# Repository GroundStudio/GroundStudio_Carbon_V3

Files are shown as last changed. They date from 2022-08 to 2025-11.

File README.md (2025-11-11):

GroundStudio Carbon V3
====================================
CYQ2 (https://ardushop.ro/en/electronics/537-placa-de-dezvoltare-carbon-v3-6427854000392.html)

Get it from [ardushop.ro](https://ardushop.ro/en/electronics/537-placa-de-dezvoltare-carbon-v3-6427854000392.html)

Explore all the GroundStudio products at [ardushop.ro](https://ardushop.ro/en/37-groundstudio)

Description
-------------------
Features ESP32 based Pico V3-02 with 2.4 GHz WiFi, V4.2 Bluetooth, 8MB SPI Flash, 2MB SPI PSRAM, 520kB internal SRAM, 448kB ROM, 18 GPIO, 12 ADC and 6 touch sensitive pins, I²C 3V3 adapter, RGB smart LED, 1 cell LiPo/LiIon battery charger with optional battery connector and CH340C for USB comunication.

Contents
-------------------

* [/Documentation](https://github.com/GroundStudio/GroundStudio_Carbon_V3/tree/main/Documentation) -- Pinout.
* [/Hardware](https://github.com/GroundStudio/GroundStudio_Carbon_V3/tree/main/Hardware) -- Schematics, layout.
* [/Arduino](https://github.com/GroundStudio/GroundStudio_Carbon_V3/tree/main/Arduino/Examples) -- Arduino test examples.

Versions
-------------------
*(Not all tags shown)*

- [REV 0.0.2]:
  - testing different uart pins setup

- [REV 0.0.3]:
  - added test point for GPIO0
  - added 100nF in parallel with R14 for better battery voltage level reading
  - adjusted the position of pin labels for better visibility

License
-------------------

This is released under the [Attribution-ShareAlike 4.0 International (CC BY-SA 4.0)](https://creativecommons.org/licenses/by-sa/4.0/) license.
**You are welcome to use this for commercial purposes.**

Please consider contributing back to this project or others to help the open-source hardware community continue to thrive and grow!

Certifications:

[Open Source Hardware Association](https://certification.oshwa.org/ro000007.html)   
   
certification-mark-RO000007-wide (https://certification.oshwa.org/ro000007.html)

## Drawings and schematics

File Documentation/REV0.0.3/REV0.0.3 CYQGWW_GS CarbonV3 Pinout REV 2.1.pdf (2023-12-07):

# GroundStudio Carbon V3

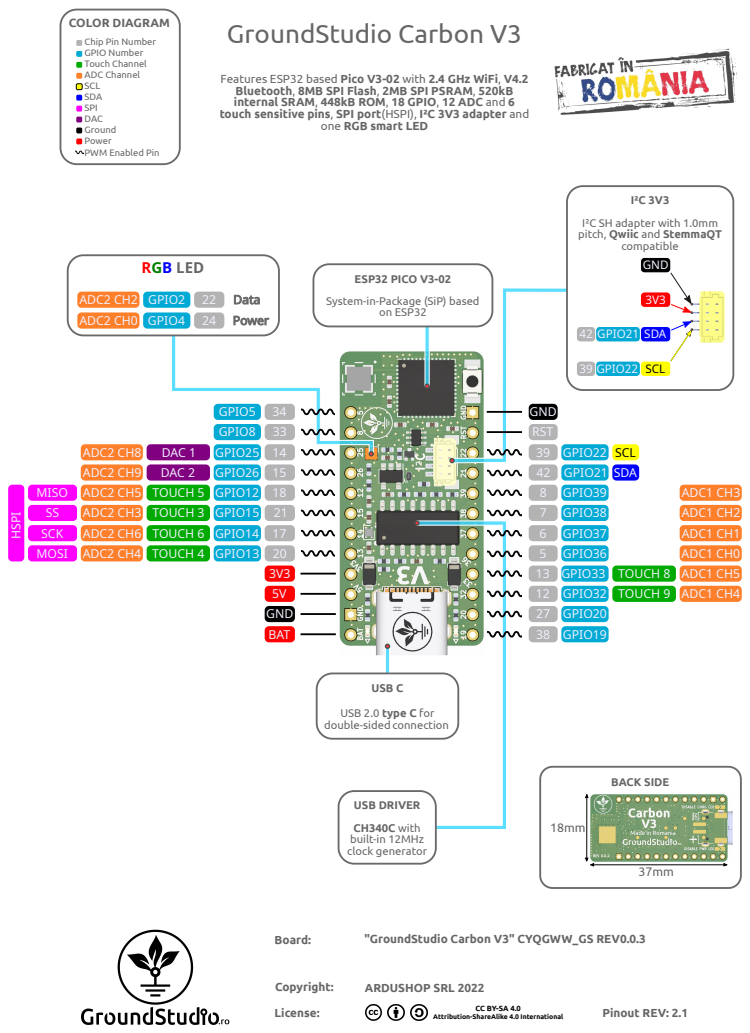
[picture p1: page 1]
COLOR DIAGRAM; Copyright:; License:; ARDUSHOP SRL 2022; Pinout REV: 2.1; Board:; "GroundStudio Carbon V3" CYQGWW_GS REV0.0.3; SCK; MISO; MOSI; on ESP32; BACK SIDE; USB C; GPIO38; GPIO37 GPIO36 GPIO33 GPIO32 GPIO20 GPIO19; 8 GPIO39; TOUCH 8 TOUCH 9; SDA; SCL; ADC1 CH1; ADC1 CH2; ADC1 CH3; ADC1 CH0 ADC1 CH5 ADC1 CH4; GND BAT; DAC 1; TOUCH 5 TOUCH 3 TOUCH 6; DAC 2; TOUCH 4; GND RST; GPIO26 GPIO12 GPIO15 GPIO14; GPIO25; GPIO8; GPIO13; GPIO5; ADC2 CH8 ADC2 CH9 ADC2 CH5 ADC2 CH3 ADC2 CH6 ADC2 CH4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

Chip Pin Number
GPIO Number
Touch Channel
ADC Channel
SCL
SDA
SPI
DAC
Ground
Power
PWM Enabled Pin

Features ESP32 based Pico V3-02 with 2.4 GHz WiFi, V4.2
Bluetooth, 8MB SPI Flash, 2MB SPI PSRAM, 520kB
internal SRAM, 448kB ROM, 18 GPIO, 12 ADC and 6
touch sensitive pins, SPI port(HSPI), I²C 3V3 adapter and

one RGB smart LED

I²C SH adapter with 1.0mm
pitch, Qwiic and StemmaQT

ESP32 PICO V3-02
System-in-Package (SiP) based

USB 2.0 type C for
double-sided connection

Attribution-ShareAlike 4.0 International

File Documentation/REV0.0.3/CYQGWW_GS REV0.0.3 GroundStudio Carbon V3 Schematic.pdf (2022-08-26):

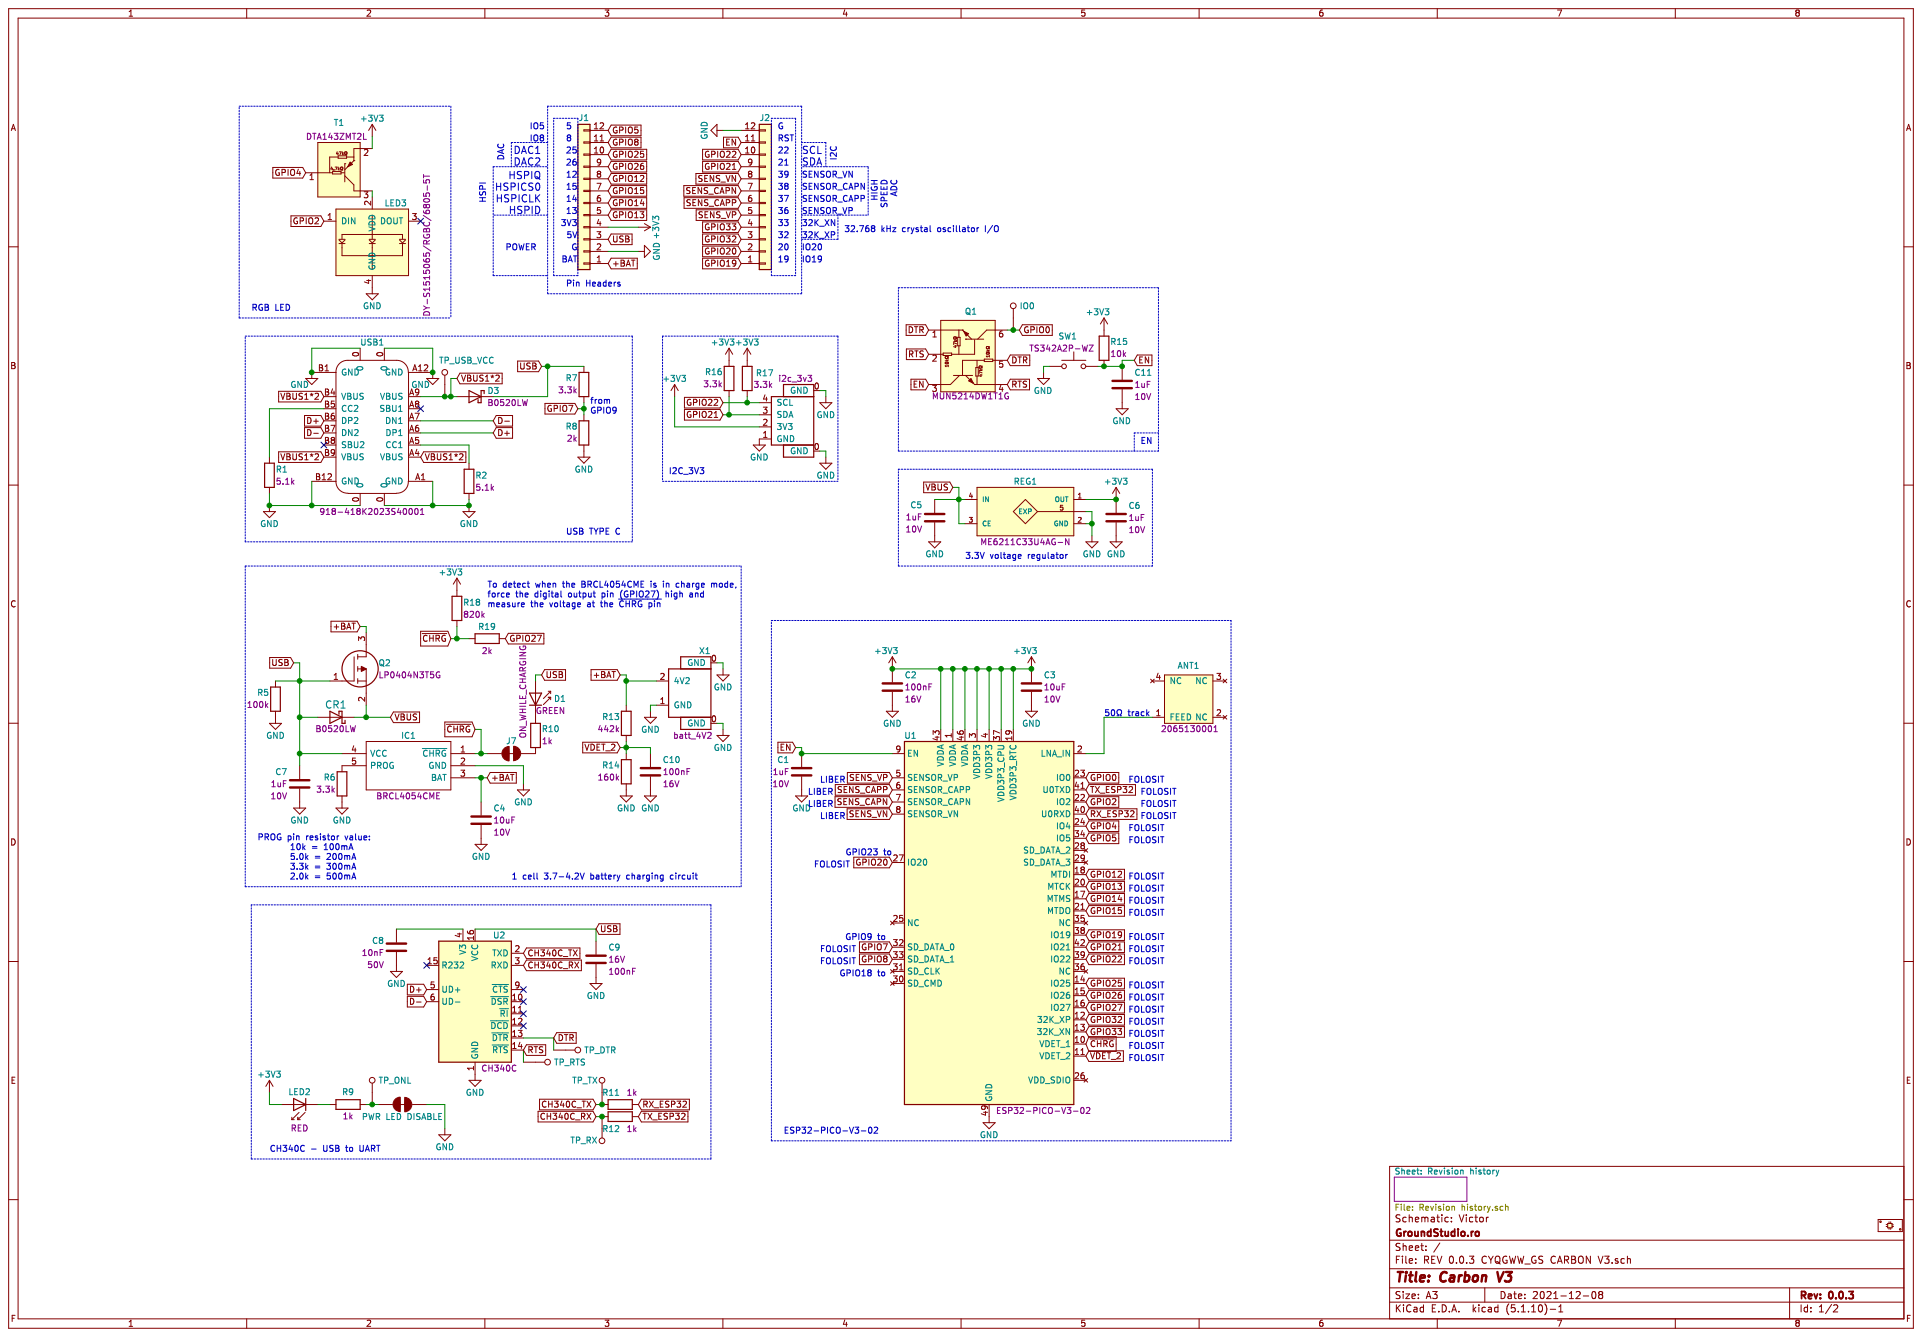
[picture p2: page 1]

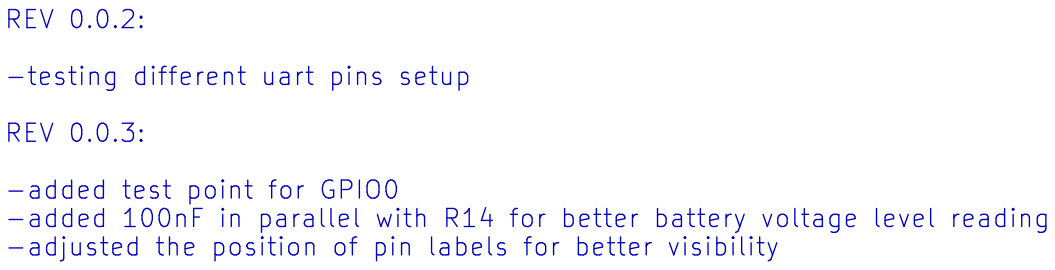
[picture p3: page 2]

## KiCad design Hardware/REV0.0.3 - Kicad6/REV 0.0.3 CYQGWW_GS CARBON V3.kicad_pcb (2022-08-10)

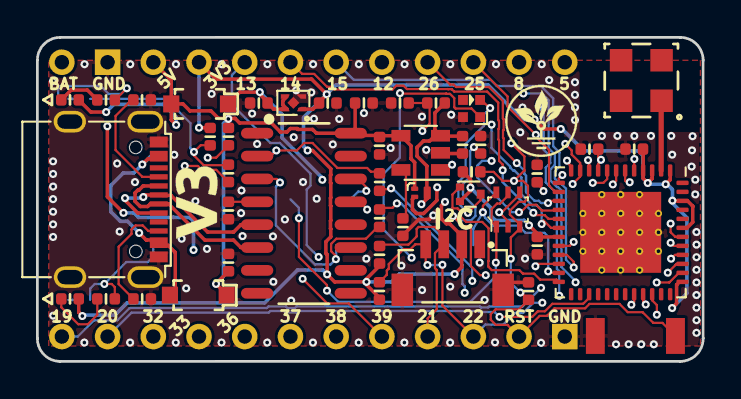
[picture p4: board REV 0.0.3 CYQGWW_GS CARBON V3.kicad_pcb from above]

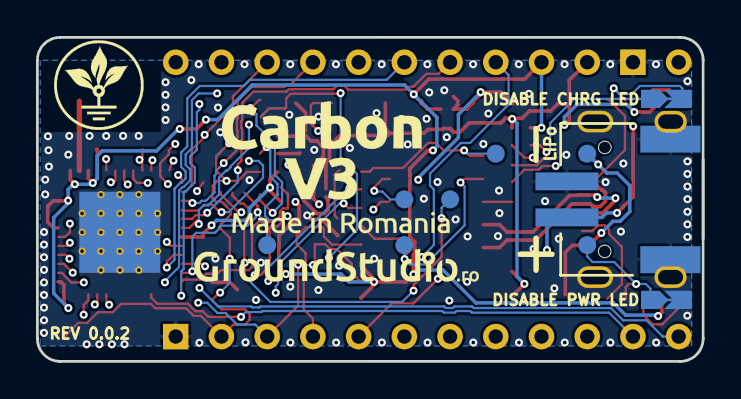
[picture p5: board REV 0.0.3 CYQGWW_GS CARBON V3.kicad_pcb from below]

Board: 4 copper layers, 37.0 x 18.0 mm, 56 parts (5 on the bottom side), 50 nets.

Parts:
ANT1: 2065130001
C1, C5, C6, C7, C11: C_0402_1uF_10V; C_0402_alt
C2, C9, C10: C_0402_100nF_16V; C_0402_alt
C3, C4: C_0402_10uF_10V; C_0402_alt
C8: C_0402_10nF_50V; C_0402_alt
CR1: SOD-123 B0520LW; SOD-123
D1: LED_0402_GREEN; LED_0402_alt
D3: SOD-123 B0520LW; SOD-123
IC1: SOT-23-5 BRCL4054CME; SOT-23-5
J1, J2: PinHeader_1x12_P2.54_V_M A2541WV-12P; PinHeader_1x12_P2.54mm_Vertical_Male
J4: PWR LED DISABLE; SolderJumper_NC
J7: disable CHARGING LED; SolderJumper_NC
LED2: LED_0402_RED; LED_0402_alt
LED3: SK6805-EC15 DY-S1515065; SK6805-EC15
Q1: SOT-363 MUN5214DW1T1G; SOT-363
Q2: SOT-883 LP0404N3T5G; SOT-883
R1, R2: R_0402_5.1k; R_0402_alt
R5: R_0402_100k; R_0402_alt
R6, R7, R16, R17: R_0402_3.3k; R_0402_alt
R8, R19: R_0402_2k; R_0402_alt
R9, R10, R11, R12: R_0402_1k; R_0402_alt
R13: R_0402_442k; R_0402_alt
R14: R_0402_160k; R_0402_alt
R15: R_0402_10k; R_0402_alt
R18: R_0402_820k; R_0402_alt
REG1: FBP1-1-4_ME6211C33U4AG-N; FBP1-1-4
SW1: TS342A2P-WZ
T1: SOT-723_DTA143ZMT2L; SOT-723
TP1: TP_RTS; TestPoint
TP2: IO0; TestPoint
TP3: TP_USB_VCC; TestPoint
TP5: TP_ONL; TestPoint
TP6: TP_TX; TestPoint
TP7: TP_RX; TestPoint
TP8: TP_DTR; TestPoint
U1: QFN-48-7x7mm ESP32-PICO-V3-02; QFN-48-1EP_7x7mm_P0.5mm_EP4.5x4.5mm
U2: SOP-16_150MIL CH340C; SOP-16_150MIL
USB1: USB_C 918-418K2023S40001; USB_C_C167321
X1: PH__1x02_P2.00mm_Horizontal C47647; PH__1x02_P2.00mm_Horizontal
X2: SH__1x04_Vertical C145961; SH__1x04_P1.00mm_Vertical

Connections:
+3V3: C2.1, C3.1, C6.1, J1.4, LED2.2, R15.2, R16.2, R17.1, R18.1, REG1.1, T1.2, U1.1, U1.3, U1.4, U1.19, U1.37, U1.43, U1.46, X2.2
+BAT: C4.1, IC1.3, J1.1, Q2.3, R13.2, X1.2
CH340C_RX: R12.2, TP7.~, U2.3
CH340C_TX: R11.2, TP6.~, U2.2
D+: U2.5, USB1.A6, USB1.B6
D-: U2.6, USB1.A7, USB1.B7
DTR: Q1.1, Q1.5, TP8.~, U2.13
EN: C1.1, C11.1, J2.11, Q1.3, R15.1, SW1.2, U1.9
GND: C1.2, C2.2, C3.2, C4.2, C5.1, C6.2, C7.2, C8.1, C9.2, C10.2, C11.2, IC1.2, J1.2, J2.12, J4.2, LED3.4, R1.2, R2.2, R5.1, R6.1, R8.1, R14.1, REG1.2, REG1.5, SW1.1, U1.49, U2.1, USB1.0, USB1.A1, USB1.A12, USB1.B1, USB1.B12, X1.0, X1.1, X2.0, X2.1
GPIO0: Q1.6, TP2.~, U1.23
GPIO2: LED3.1, U1.22
GPIO4: T1.1, U1.24
GPIO5: J1.12, U1.34
GPIO7: R7.1, R8.2, U1.32
GPIO8: J1.11, U1.33
GPIO12: J1.8, U1.18
GPIO13: J1.5, U1.20
GPIO14: J1.6, U1.17
GPIO15: J1.7, U1.21
GPIO19: J2.1, U1.38
GPIO20: J2.2, U1.27
GPIO21: J2.9, R16.1, U1.42, X2.3
GPIO22: J2.10, R17.2, U1.39, X2.4
GPIO25: J1.10, U1.14
GPIO26: J1.9, U1.15
GPIO27: R19.2, U1.16
GPIO32: J2.3, U1.12
GPIO33: J2.4, U1.13
unnamed: ANT1.1, U1.2
unnamed: C8.2, U2.4
unnamed: D1.1, R10.2
unnamed: IC1.5, R6.2
unnamed: J4.1, R9.2, TP5.~
unnamed: J7.2, R10.1
unnamed: LED2.1, R9.1
unnamed: LED3.2, T1.3
unnamed: R1.1, USB1.B5
unnamed: R2.1, USB1.A5
RTS: Q1.2, Q1.4, TP1.~, U2.14
RX_ESP32: R11.1, U1.40
SENS_CAPN: J2.7, U1.7
SENS_CAPP: J2.6, U1.6
SENS_VN: J2.8, U1.8
SENS_VP: J2.5, U1.5
TX_ESP32: R12.1, U1.41
USB: C7.1, C9.1, CR1.2, D1.2, D3.1, IC1.4, J1.3, Q2.1, R5.2, R7.2, U2.16
VBUS: C5.2, CR1.1, Q2.2, REG1.3, REG1.4
VBUS1*2: D3.2, TP3.~, USB1.A4, USB1.A9, USB1.B4, USB1.B9
VDET_2: C10.1, R13.1, R14.2, U1.11
~CHRG: IC1.1, J7.1, R18.2, R19.1, U1.10

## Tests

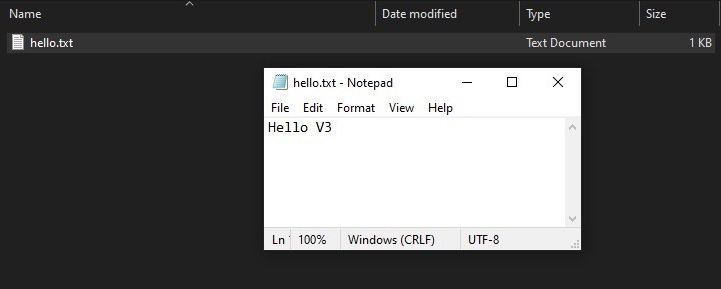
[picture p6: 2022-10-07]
Arduino/Examples/HSPI_SD_card_test/SD test result file.jpg

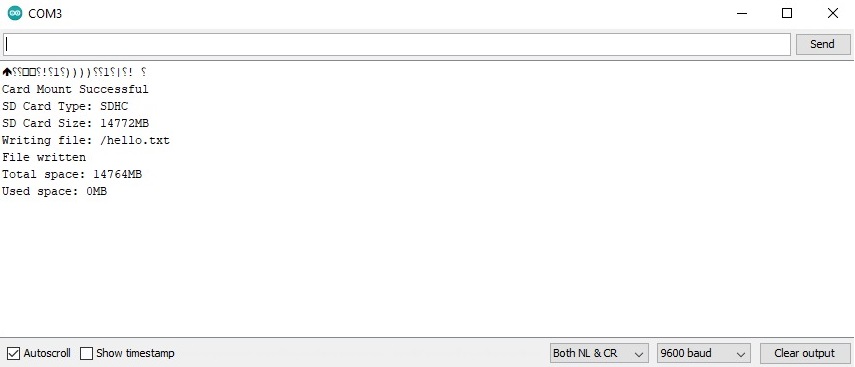
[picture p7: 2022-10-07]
Arduino/Examples/HSPI_SD_card_test/SD test serial monitor.jpg

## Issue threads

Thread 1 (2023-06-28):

Eroare conectare la Modul SD

FilipLupaescu, 2023-06-28:
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

Când rulez programul din exemplul pentru a testa modulul SD, în primul rând când modulul e conectat primesc eroarea:
`WARNING: Failed to communicate with the flash chip, read/write operations will fail. Try checking the chip connections or removing any other hardware connected to IOs.`
pe site-ul [espressif](https://docs.espressif.com/projects/esp-idf/en/latest/esp32/api-reference/peripherals/sd_pullup_requirements.html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) spune:
>On boards using the internal regulator and a 3.3 V flash chip, GPIO12 must be pulled low at reset. This is incompatible with the SD card >operation.

Dacă scot pinul 12 si il conectez doar după reset:

	rst:0x10 (RTCWDT_RTC_RESET),boot:0x37 (SPI_FAST_FLASH_BOOT)
	14:41:31.868 > invalid header: 0xffffffff
	14:41:31.912 > invalid header: 0xffffffff
	14:41:31.957 > invalid header: 0xffffffff

De aceea am încercat cu alți pini pentru SPI, `spiSD.begin(14, 13, 25, SD_CS); // CLK, MISO, MOSI, SS` (apropo ați greșit ordinea în acest comment în exemplu), dar priesc alte erori:

	14:50:15.332 > [   769][E][sd_diskio.cpp:802] sdcard_mount(): f_mount failed: (3) The physical drive cannot work
	14:50:15.832 > [  1269][E][sd_diskio.cpp:126] sdSelectCard(): Select Failed
	14:50:15.835 > Card Mount Failed

M-ați putea ajuta? Vă mulțumesc.

----------

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

When I run the program to test the SD module, first, when the module is connected, I receive the error:
`WARNING: Failed to communicate with the flash chip, read/write operations will fail. Try checking the chip connections or removing any other hardware connected to IOs.`
    On the [Espressif website](https://docs.espressif.com/projects/esp-idf/en/latest/esp32/api-reference/peripherals/sd_pullup_requirements.html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), it says:
>On boards using the internal regulator and a 3.3 V flash chip, GPIO12 must be pulled low at reset. This is incompatible with the SD card >operation.

If I remove pin 12 and connect it only after reset:

	rst:0x10 (RTCWDT_RTC_RESET),boot:0x37 (SPI_FAST_FLASH_BOOT)
	14:41:31.868 > invalid header: 0xffffffff
	14:41:31.912 > invalid header: 0xffffffff
	14:41:31.957 > invalid header: 0xffffffff

That's why I tried using other pins for SPI, `spiSD.begin(14, 13, 25, SD_CS); // CLK, MISO, MOSI, SS` (by the way, you made a mistake in the pin order in this comment in the example), but I still get an error:

    14:50:15.332 > [ 769][E][sd_diskio.cpp:802] sdcard_mount(): f_mount failed: (3) The physical drive cannot work
    14:50:15.832 > [ 1269][E][sd_diskio.cpp:126] sdSelectCard(): Select Failed
    14:50:15.835 > Card Mount Failed

 Can you help me with these errors? Thank you.

FilipLupaescu, 2023-06-29:
Bună,

Aici sunt conexiunile după cum este specificat pe ArduShop.ro:

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

În acest mod nu pot încărca codul, primesc acest mesaj la output:

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

Dacă deconectez pinul 12 și îl conectez după uploadarea codului, am aceasta în Serial Monitor:

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

Pentru a putea rula codul, am folosit pinul 26 în loc de 12:

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

și primesc aceasta în Serial Monitor:

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

Acesta este cardul folosit, formatat in FAT32:

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

Setările din Arduino->Tools:

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

Portul conectat din Device Manager:

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

Codul folosit este identic cu cel din exemplu cu singura modificare fiind la `Serial.begin(115200);` în loc de 9600, pentru a putea vedea boot log ("invalid" header când GPIO12 e conectat la Modulul SD), și `spiSD.begin(14, 13, 26, SD_CS);` 26 în loc de 12 desigur.
```cpp
#include "FS.h"
#include "SD.h"
#include "SPI.h"

SPIClass spiSD(HSPI);

#define SD_CS 15

void writeFile(fs::FS &fs, const char * path, const char * message){
    Serial.printf("Writing file: %s\n", path);

    File file = fs.open(path, FILE_WRITE);
    if(!file){
        Serial.println("Failed to open file for writing");
        return;
    }
    if(file.print(message)){
        Serial.println("File written");
    } else {
        Serial.println("Write failed");
    }
    file.close();
}

void setup()
{
  Serial.begin(115200);
  Serial.println();
  SPI.end();
  spiSD.begin(14, 13, 26, SD_CS); //CLK,MOSI,MISO,SS
  if (!SD.begin(SD_CS, spiSD))
  {
    Serial.println("Card Mount Failed");
    return;
  }
  else
  {
    Serial.println("Card Mount Successful");
  }

  uint8_t cardType = SD.cardType();

  Serial.print("SD Card Type: ");
  if(cardType == CARD_MMC){
        Serial.println("MMC");
    } else if(cardType == CARD_SD){
        Serial.println("SDSC");
    } else if(cardType == CARD_SDHC){
        Serial.println("SDHC");
    } else {
        Serial.println("UNKNOWN");
    }

    uint64_t cardSize = SD.cardSize() / (1024 * 1024);
    Serial.printf("SD Card Size: %lluMB\n", cardSize);

  writeFile(SD, "/hello V3.txt", "Hello V3");
  Serial.printf("Total space: %lluMB\n", SD.totalBytes() / (1024 * 1024));
  Serial.printf("Used space: %lluMB\n", SD.usedBytes() / (1024 * 1024));
}

void loop()
{ }
```

Cardul nu conține nimic după rularea codului:

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

victor1115, 2023-07-07:
Bună ziua,

Ne cerem scuze pentru răspunsul întârziat.
Din testele noastre am observat că eroarea este cauzată de ordinea pinilor în spiSD.begin de la linia 30.

Vă rugăm să modificați această linie astfel:
Înainte: spiSD.begin(14, 13, 12, SD_CS); //CLK,MOSI,MISO,SS
După: spiSD.begin(14, 12, 13, SD_CS); //SCK, MISO, MOSI, SS

Conexiunile hardware rămân neschimbate, doar această linie trebuie modificată.
După încărcarea codului vă rugăm să reveniți cu rezultatul obținut de dvs.

Numai bine,
Ardushop.ro
Victor Nicula

FilipLupaescu, 2023-07-07:
Bună,

Cu `spiSD.begin(14, 12, 13, SD_CS); //SCK, MISO, MOSI, SS` e același lucru, nu pot folosi pinul 12.

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

Am folosit în schimb pinul 26 in loc de 12 `spiSD.begin(14, 26, 13, SD_CS); //SCK, MISO, MOSI, SS` și așa funcționează.

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

Vă mulțumesc,
Filip

Closed 2023-07-07.

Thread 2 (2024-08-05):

Poor WiFi signal

leonardpitzu, 2024-08-05:
I have a few of these boards and everything is working great except for the WiFi signal strength. All devices in my network (unifi AP's) have great signal except for these boards. Just as an example one board is about 20cm away from the AP and the signal strength is -85dBm.
Any way to debug or fix this? Any way to tweak the boards and add an external antenna?

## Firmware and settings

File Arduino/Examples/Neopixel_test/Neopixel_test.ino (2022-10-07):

// A basic everyday NeoPixel strip test program.

// NEOPIXEL BEST PRACTICES for most reliable operation:
// - Add 1000 uF CAPACITOR between NeoPixel strip's + and - connections.
// - MINIMIZE WIRING LENGTH between microcontroller board and first pixel.
// - NeoPixel strip's DATA-IN should pass through a 300-500 OHM RESISTOR.
// - AVOID connecting NeoPixels on a LIVE CIRCUIT. If you must, ALWAYS
//   connect GROUND (-) first, then +, then data.
// - When using a 3.3V microcontroller with a 5V-powered NeoPixel strip,
//   a LOGIC-LEVEL CONVERTER on the data line is STRONGLY RECOMMENDED.
// (Skipping these may work OK on your workbench but can fail in the field)

#include <Adafruit_NeoPixel.h>
#ifdef __AVR__
 #include <avr/power.h> // Required for 16 MHz Adafruit Trinket
#endif

// Which pin on the Arduino is connected to the NeoPixels?
// On a Trinket or Gemma we suggest changing this to 1:
#define LED_PIN    2
#define LED_ENABLE_PIN 4

// How many NeoPixels are attached to the Arduino?
#define LED_COUNT 1

// Declare our NeoPixel strip object:
Adafruit_NeoPixel strip(LED_COUNT, LED_PIN, NEO_GRB + NEO_KHZ800);
// Argument 1 = Number of pixels in NeoPixel strip
// Argument 2 = Arduino pin number (most are valid)
// Argument 3 = Pixel type flags, add together as needed:
//   NEO_KHZ800  800 KHz bitstream (most NeoPixel products w/WS2812 LEDs)
//   NEO_KHZ400  400 KHz (classic 'v1' (not v2) FLORA pixels, WS2811 drivers)
//   NEO_GRB     Pixels are wired for GRB bitstream (most NeoPixel products)
//   NEO_RGB     Pixels are wired for RGB bitstream (v1 FLORA pixels, not v2)
//   NEO_RGBW    Pixels are wired for RGBW bitstream (NeoPixel RGBW products)


// setup() function -- runs once at startup --------------------------------

void setup() {
  pinMode(LED_ENABLE_PIN, OUTPUT);
  digitalWrite(LED_ENABLE_PIN, 0);
  // These lines are specifically to support the Adafruit Trinket 5V 16 MHz.
  // Any other board, you can remove this part (but no harm leaving it):
#if defined(__AVR_ATtiny85__) && (F_CPU == 16000000)
  clock_prescale_set(clock_div_1);
#endif
  // END of Trinket-specific code.

  strip.begin();           // INITIALIZE NeoPixel strip object (REQUIRED)
  strip.show();            // Turn OFF all pixels ASAP
  strip.setBrightness(50); // Set BRIGHTNESS to about 1/5 (max = 255)
}


// loop() function -- runs repeatedly as long as board is on ---------------

void loop() {
  // Fill along the length of the strip in various colors...
  colorWipe(strip.Color(255,   0,   0), 50); // Red
  colorWipe(strip.Color(  0, 255,   0), 50); // Green
  colorWipe(strip.Color(  0,   0, 255), 50); // Blue

  // Do a theater marquee effect in various colors...
  theaterChase(strip.Color(127, 127, 127), 50); // White, half brightness
  theaterChase(strip.Color(127,   0,   0), 50); // Red, half brightness
  theaterChase(strip.Color(  0,   0, 127), 50); // Blue, half brightness

  rainbow(10);             // Flowing rainbow cycle along the whole strip
  theaterChaseRainbow(50); // Rainbow-enhanced theaterChase variant
}


// Some functions of our own for creating animated effects -----------------

// Fill strip pixels one after another with a color. Strip is NOT cleared
// first; anything there will be covered pixel by pixel. Pass in color
// (as a single 'packed' 32-bit value, which you can get by calling
// strip.Color(red, green, blue) as shown in the loop() function above),
// and a delay time (in milliseconds) between pixels.
void colorWipe(uint32_t color, int wait) {
  for(int i=0; i<strip.numPixels(); i++) { // For each pixel in strip...
    strip.setPixelColor(i, color);         //  Set pixel's color (in RAM)
    strip.show();                          //  Update strip to match
    delay(wait);                           //  Pause for a moment
  }
}

// Theater-marquee-style chasing lights. Pass in a color (32-bit value,
// a la strip.Color(r,g,b) as mentioned above), and a delay time (in ms)
// between frames.
void theaterChase(uint32_t color, int wait) {
  for(int a=0; a<10; a++) {  // Repeat 10 times...
    for(int b=0; b<3; b++) { //  'b' counts from 0 to 2...
      strip.clear();         //   Set all pixels in RAM to 0 (off)
      // 'c' counts up from 'b' to end of strip in steps of 3...
      for(int c=b; c<strip.numPixels(); c += 3) {
        strip.setPixelColor(c, color); // Set pixel 'c' to value 'color'
      }
      strip.show(); // Update strip with new contents
      delay(wait);  // Pause for a moment
    }
  }
}

// Rainbow cycle along whole strip. Pass delay time (in ms) between frames.
void rainbow(int wait) {
  // Hue of first pixel runs 5 complete loops through the color wheel.
  // Color wheel has a range of 65536 but it's OK if we roll over, so
  // just count from 0 to 5*65536. Adding 256 to firstPixelHue each time
  // means we'll make 5*65536/256 = 1280 passes through this outer loop:
  for(long firstPixelHue = 0; firstPixelHue < 5*65536; firstPixelHue += 256) {
    for(int i=0; i<strip.numPixels(); i++) { // For each pixel in strip...
      // Offset pixel hue by an amount to make one full revolution of the
      // color wheel (range of 65536) along the length of the strip
      // (strip.numPixels() steps):
      int pixelHue = firstPixelHue + (i * 65536L / strip.numPixels());
      // strip.ColorHSV() can take 1 or 3 arguments: a hue (0 to 65535) or
      // optionally add saturation and value (brightness) (each 0 to 255).
      // Here we're using just the single-argument hue variant. The result
      // is passed through strip.gamma32() to provide 'truer' colors
      // before assigning to each pixel:
      strip.setPixelColor(i, strip.gamma32(strip.ColorHSV(pixelHue)));
    }
    strip.show(); // Update strip with new contents
    delay(wait);  // Pause for a moment
  }
}

// Rainbow-enhanced theater marquee. Pass delay time (in ms) between frames.
void theaterChaseRainbow(int wait) {
  int firstPixelHue = 0;     // First pixel starts at red (hue 0)
  for(int a=0; a<30; a++) {  // Repeat 30 times...
    for(int b=0; b<3; b++) { //  'b' counts from 0 to 2...
      strip.clear();         //   Set all pixels in RAM to 0 (off)
      // 'c' counts up from 'b' to end of strip in increments of 3...
      for(int c=b; c<strip.numPixels(); c += 3) {
        // hue of pixel 'c' is offset by an amount to make one full
        // revolution of the color wheel (range 65536) along the length
        // of the strip (strip.numPixels() steps):
        int      hue   = firstPixelHue + c * 65536L / strip.numPixels();
        uint32_t color = strip.gamma32(strip.ColorHSV(hue)); // hue -> RGB
        strip.setPixelColor(c, color); // Set pixel 'c' to value 'color'
      }
      strip.show();                // Update strip with new contents
      delay(wait);                 // Pause for a moment
      firstPixelHue += 65536 / 90; // One cycle of color wheel over 90 frames
    }
  }
}

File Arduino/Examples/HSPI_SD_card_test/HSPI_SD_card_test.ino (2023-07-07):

#include "FS.h"
#include "SD.h"
#include "SPI.h"

SPIClass spiSD(HSPI);

#define SD_CS 15

void writeFile(fs::FS &fs, const char * path, const char * message){
    Serial.printf("Writing file: %s\n", path);

    File file = fs.open(path, FILE_WRITE);
    if(!file){
        Serial.println("Failed to open file for writing");
        return;
    }
    if(file.print(message)){
        Serial.println("File written");
    } else {
        Serial.println("Write failed");
    }
    file.close();
}

void setup()
{
  Serial.begin(9600);
  Serial.println();
  SPI.end(); 
  spiSD.begin(14, 12, 13, SD_CS); //SCK, MISO, MOSI, SS
  if (!SD.begin(SD_CS, spiSD))
  {
    Serial.println("Card Mount Failed");
    return;
  }
  else
  {
    Serial.println("Card Mount Successful");
  }

  uint8_t cardType = SD.cardType();

  Serial.print("SD Card Type: ");
  if(cardType == CARD_MMC){
        Serial.println("MMC");
    } else if(cardType == CARD_SD){
        Serial.println("SDSC");
    } else if(cardType == CARD_SDHC){
        Serial.println("SDHC");
    } else {
        Serial.println("UNKNOWN");
    }

    uint64_t cardSize = SD.cardSize() / (1024 * 1024);
    Serial.printf("SD Card Size: %lluMB\n", cardSize);
    
  writeFile(SD, "/hello V3.txt", "Hello V3");
  Serial.printf("Total space: %lluMB\n", SD.totalBytes() / (1024 * 1024));
  Serial.printf("Used space: %lluMB\n", SD.usedBytes() / (1024 * 1024));
}

void loop()
{ }

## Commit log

2022-08-10 - initial commit
    [REV 0.0.3 CYQGWW_GS CARBON V3.kicad_pcb, REV 0.0.3 CYQGWW_GS CARBON V3.kicad_sch, Revision history.kicad_sch]
2022-08-26 - added schematic pdf file
2022-08-26 - added "Kicad6" to revision folder name
    [REV 0.0.3 CYQGWW_GS CARBON V3.kicad_pcb, REV 0.0.3 CYQGWW_GS CARBON V3.kicad_sch, Revision history.kicad_sch]
2022-10-07 - updated pinout to REV 2 - added arduino examples
2022-12-21 - added example for reading battery level
2023-07-07 Update HSPI_SD_card_test.ino
    fixed a typo on line 30 wich caused ESP32 to enter a boot loop.
    [HSPI_SD_card_test.ino]
2023-10-26 - added .step 3D file of the board
